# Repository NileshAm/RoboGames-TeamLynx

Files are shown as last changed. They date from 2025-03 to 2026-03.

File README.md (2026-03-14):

# TeamLynx

<p align="center">
  
</p>

<p align="center">
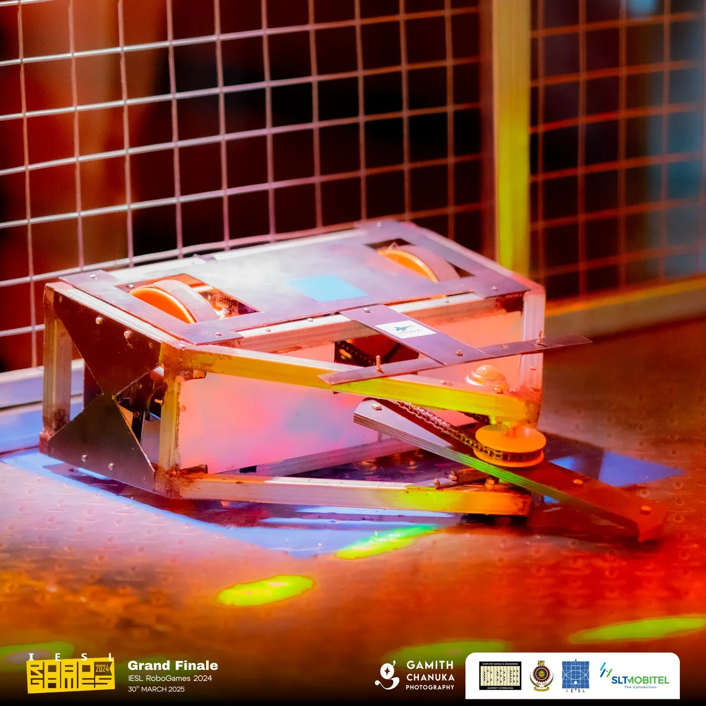
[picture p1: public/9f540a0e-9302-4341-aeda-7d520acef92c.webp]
  
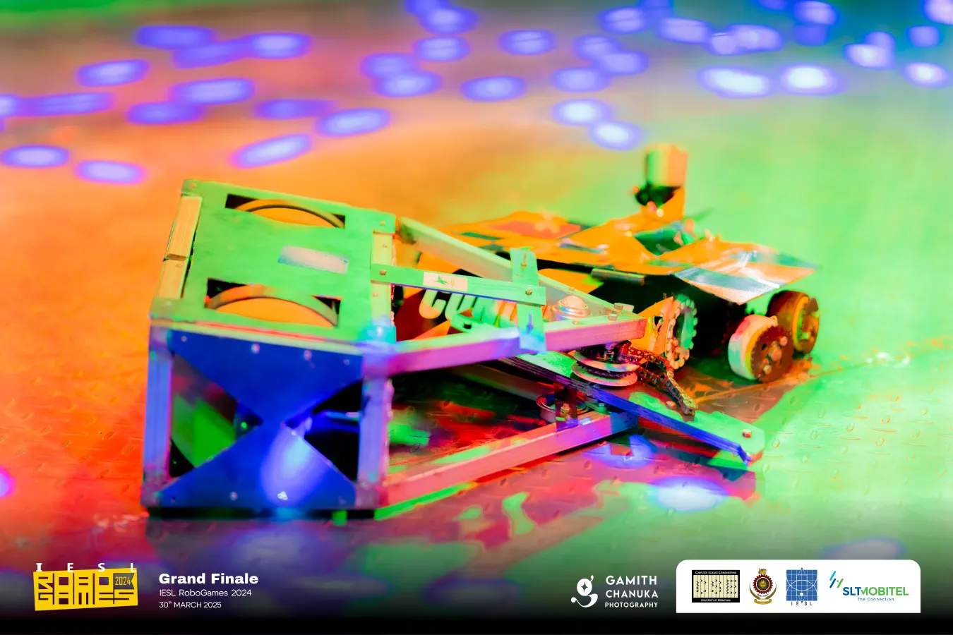
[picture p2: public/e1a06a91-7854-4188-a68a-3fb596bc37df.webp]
  
</p>

In this repository contains the project files for the Team-Lynx battlebot. 

## About
* All the 3D modelling and design is done through solidworks. Assembly can be found [here](drawings-pdf\AssemblyV2.pdf).
* The PCB design use done by using Altium designer.
* Firmware is being ran on a STM32 blue pill for its high performance characteristics.

## Project Structure

```
└── 📁RoboGames-TeamLynx
    └── 📁code
        ├── code.ino
        ├── motor_control.h
        ├── pins.h
        ├── receiver.h
        ├── restart.h
    └── 📁downloads
        └── 📁5840-31zys-1.snapshot.6
            ├── M8 long shaft.stl
            ├── STD D-Shaft.stl
        └── 📁8mm-lead-screw-with-nut-1.snapshot.2
            ├── LeadScrew 8mm x 2mmPitch.JPG
            ├── LeadScrew 8mm x 2mmPitch.SLDPRT
            ├── LeadScrew 8mm x 2mmPitch.STEP
            ├── LeadScrew Nut 8mm x 2mmPitch.JPG
            ├── LeadScrew Nut 8mm x 2mmPitch.SLDPRT
            ├── LeadScrew Nut 8mm x 2mmPitch.STEP
        └── 📁arduino-mega-2560--1.snapshot.8
            ├── ArduinoMega_STEP_AP203.STEP
            ├── ArduinoMega.SLDPRT
        └── 📁arduino-nano-7.snapshot.2
            ├── arduino nano.SLDPRT
        └── 📁avian-4250-800kv-outrunner-brushless....
            └── 📁Outrunner Motor
            ├── Outrunner Motor.STEP
            ├── Screenshot 2023-02-23 193953.png
        └── 📁bts7960-43a-high-power-h-.....
            ├── 8 PIN HEADER, IC, .....
            ├── ALUMINUM ELECTROLYTIC ...
        └── 📁dc-motor-zy6812-100-120w-1.snapshot.4
            ├── DC motor zy6812 100w.SLDPRT
            ├── DC motor zy6812 100w.STEP
            ├── untitled.26.jpg
        └── 📁kfl08-8mm-zinc-aluminum-alloy-....
        └── 📁simple-box-bar-frame-1.snapshot.1
            ├── 11 Table Frame.SLDPRT
    └── 📁drawings
        ├── arduino nano.SLDDRW
        ├── Assembly.SLDDRW
        ├── AssemblyV2.SLDDRW
        .
        .
        .
    └── 📁drawings-pdf
        ├── ArduinoNano.pdf
        ├── ArmourAnnotations.png
        .
        .
        .
        .
    └── 📁laserCutFiles
        ├── BackArmourPlate.DXF
        ├── BottomArmourPlatex2.DXF
        ├── CasterMountx2.DXF
        .
        .
        .
        .
    └── 📁Parts
        └── 📁Vis
            ├── Assembly.mp4
        ├── AcralicPlate.SLDPRT
        ├── arduino nano.SLDPRT
        .
        .
        .
        .
    └── 📁PCB
        └── 📁Lync-main-board
            └── 📁__Previews
                ├── Schematic.SchDocPreview
            └── 📁Integrated Library
                └── 📁ALSR0310K00FE12
                    ├── ALSR0310K00FE12.SchLib
                    ├── ALSR0310K00FE12.STEP
                    ├── RESAD1869W81L1270D457.PcbLib
                .
                .
                .
            └── 📁PCB library
                ├── LM2596S.PcbLib
            └── 📁Schematic library
                ├── LM2596S.SchLib
            ├── 2layer-2oz.RUL
            ├── Logo.png
            ├── Lync-main-board.PrjPcb
            ├── Lync-main-board.PrjPcbStructure
            ├── PCB.PcbDoc
            ├── schematic.pdf
            ├── Schematic.SchDoc
        ├── Lync-main-board.zip
    └── 📁public
        ├── 9f540a0e-9302-4341-aeda-7d520acef92c.webp
        ├── Assembly.glb
        ├── AssemblyV2.STEP
        ├── e1a06a91-7854-4188-a68a-3fb596bc37df.webp
    └── 📁sheet metal parts
        ├── Back brace.SLDPRT
        ├── Back horizontal brace.SLDPRT
        ├── Back plate.SLDPRT
        ├── blade mount.SLDASM
        ├── Bottom brace.SLDPRT
        ├── motor mount level 1.SLDPRT
        ├── motor mount level 2.SLDPRT
        ├── motor mount level 3.SLDPRT
        ├── Top brace.SLDPRT
    ├── .gitignore
    ├── LYNX logo.jpg
    └── README.md
```

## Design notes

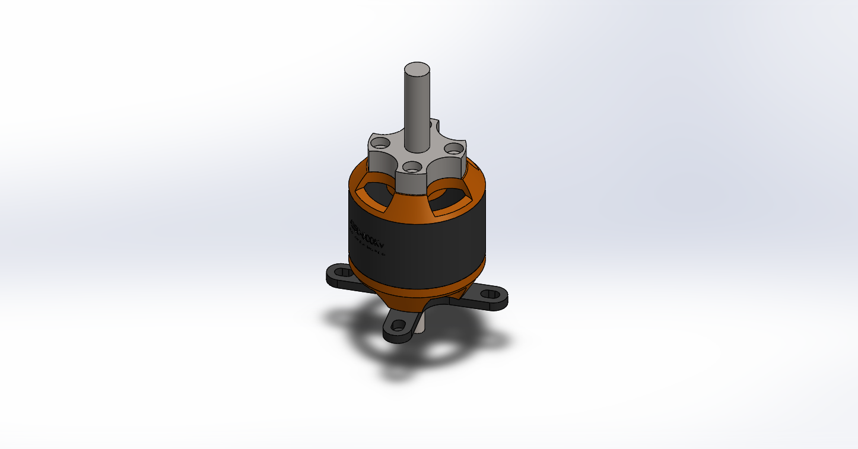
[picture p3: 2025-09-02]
downloads/avian-4250-800kv-outrunner-brushless-motor-1.snapshot.3/Screenshot 2023-02-23 193953.png

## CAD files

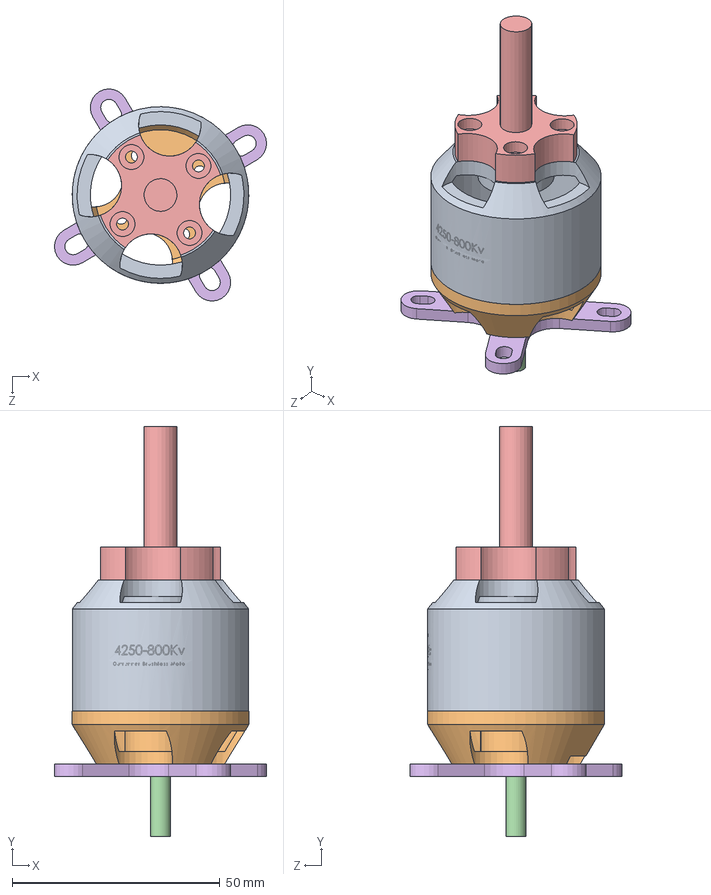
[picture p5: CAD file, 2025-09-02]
downloads/avian-4250-800kv-outrunner-brushless-motor-1.snapshot.3/Outrunner Motor/Outrunner Motor.SLDASM
51.0 x 98.6 x 51.0 mm
Outrunner Brushless Motor Top
Outrunner Brushless Motor Bottom
SimpleBearing
3.16Rod
PropShaft
MotorCrossBar

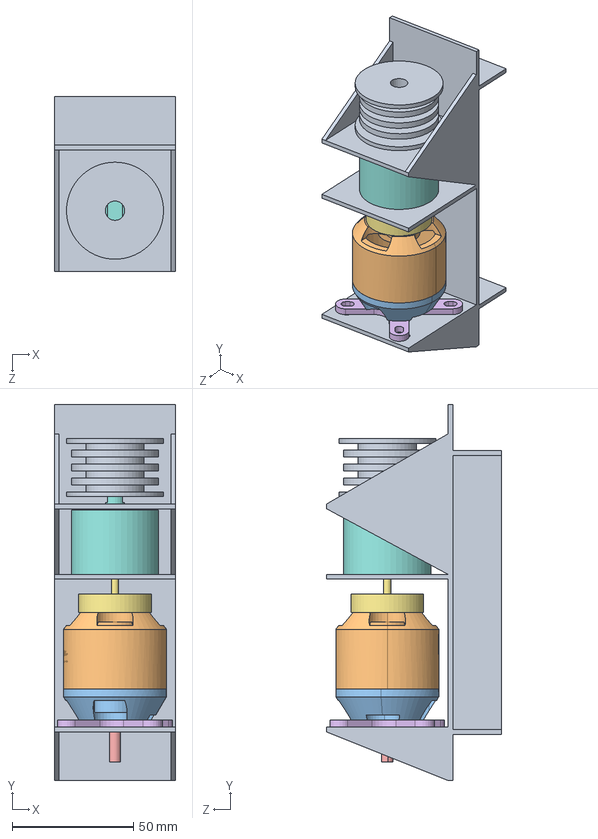
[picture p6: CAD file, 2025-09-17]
Parts/BladeMotorAssembly.SLDASM
50.0 x 155.0 x 72.0 mm
BladeMotorMount
Outrunner Brushless Motor Top.STEP
Outrunner Brushless Motor Bottom.STEP
SimpleBearing.STEP
3.16Rod.STEP
MotorCrossBar.STEP
BladeShaft
Gearbox
BladeMotorPulley

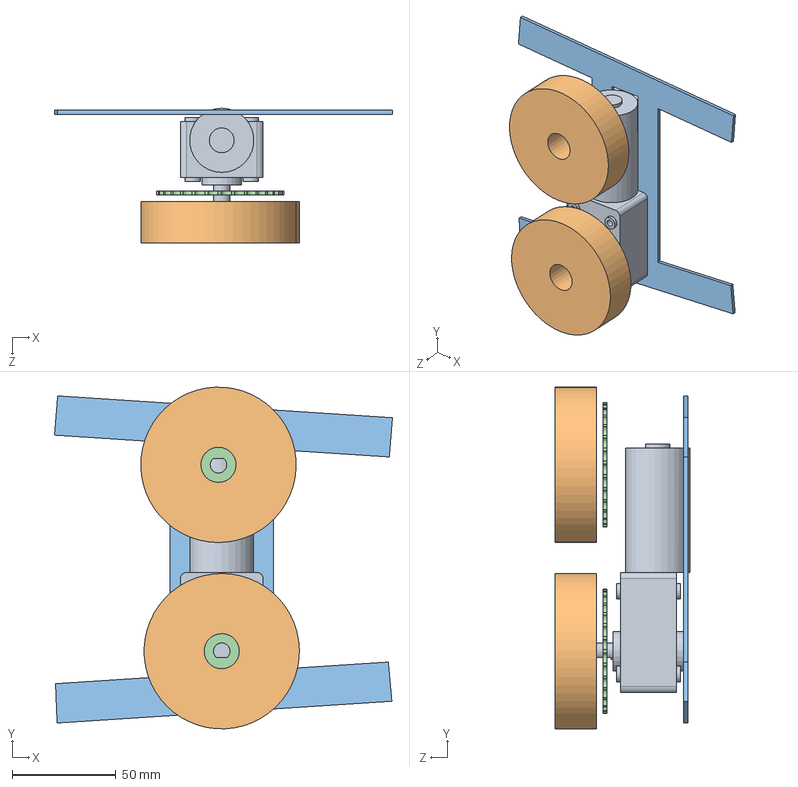
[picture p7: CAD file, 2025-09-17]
Parts/WheelMotorAssembly.SLDASM
163.2 x 164.9 x 65.0 mm
WheelMotor
Wheel x 2
motor mount
Sproket x 2

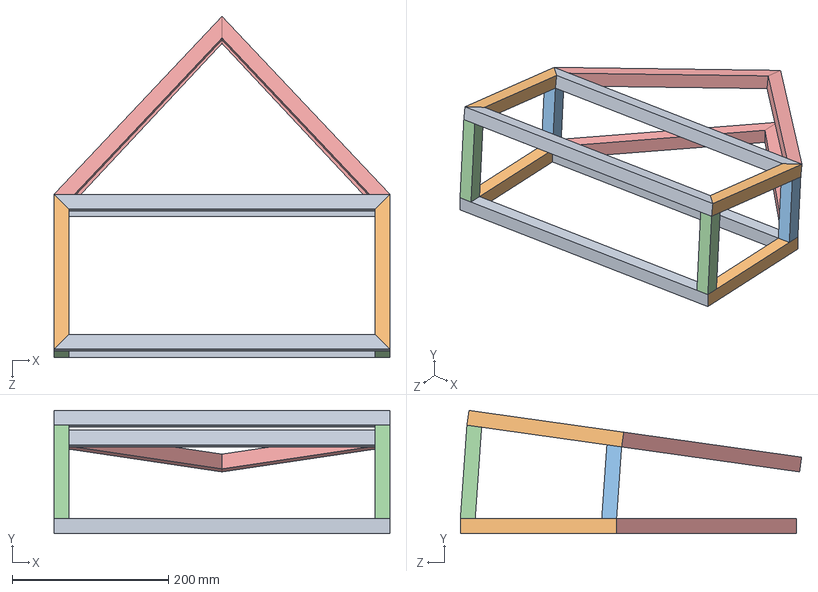
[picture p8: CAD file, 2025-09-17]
Parts/Frame.SLDASM
430.0 x 157.6 x 436.8 mm
FrontFrame x 4
RightFrame x 4
HeightFrameFront x 2
HeightFrame x 2
FrontSupportFrame x 4

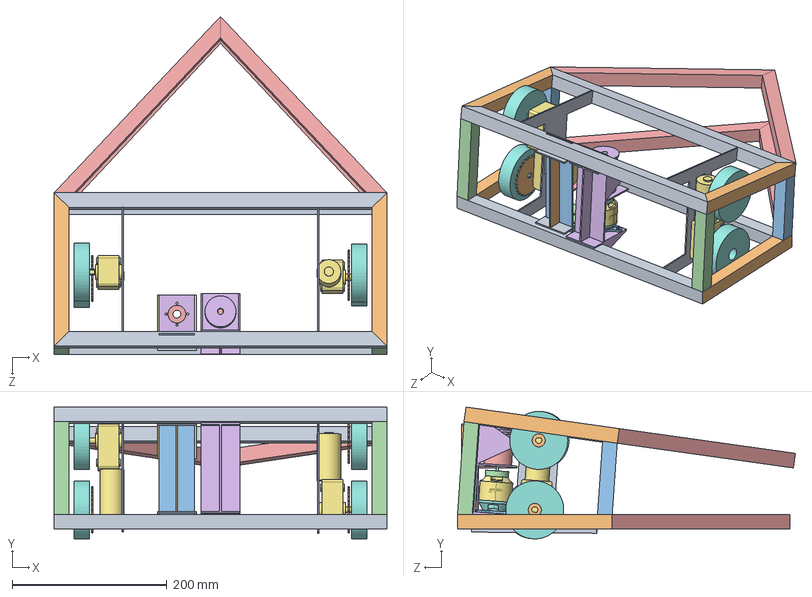
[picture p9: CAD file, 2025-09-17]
Parts/AssemblyV2.SLDASM
430.0 x 170.4 x 436.8 mm
FrontFrame x 4
RightFrame x 4
HeightFrameFront x 2
HeightFrame x 2
FrontSupportFrame x 4
BladeMotorMount
Outrunner Brushless Motor Top.STEP
Outrunner Brushless Motor Bottom.STEP
SimpleBearing.STEP
3.16Rod.STEP
MotorCrossBar.STEP
BladeShaft
Gearbox
BladeMotorPulley
WheelMotor x 2
Wheel x 4
motor mount x 2
Sproket x 2
Back plate
motor mount level 1
motor mount level 2
motor mount level 3
Top brace x 2
Bottom brace x 2
Back horizontal brace x 2
Back brace

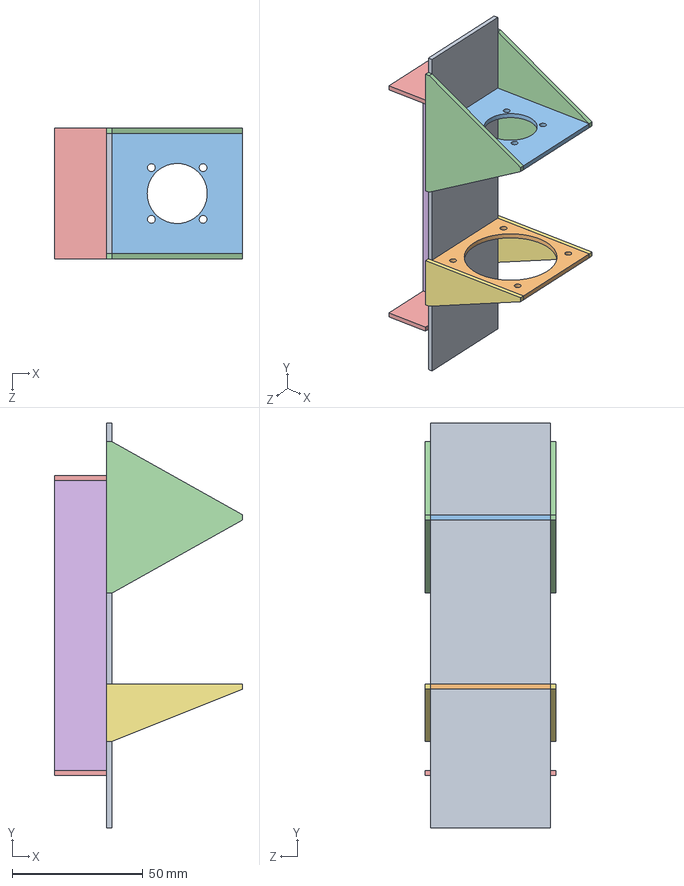
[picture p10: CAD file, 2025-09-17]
sheet metal parts/blade mount.SLDASM
72.0 x 155.0 x 50.0 mm
Back plate
motor mount level 2
motor mount level 3
Top brace x 2
Back horizontal brace x 2
Back brace
Bottom brace x 2

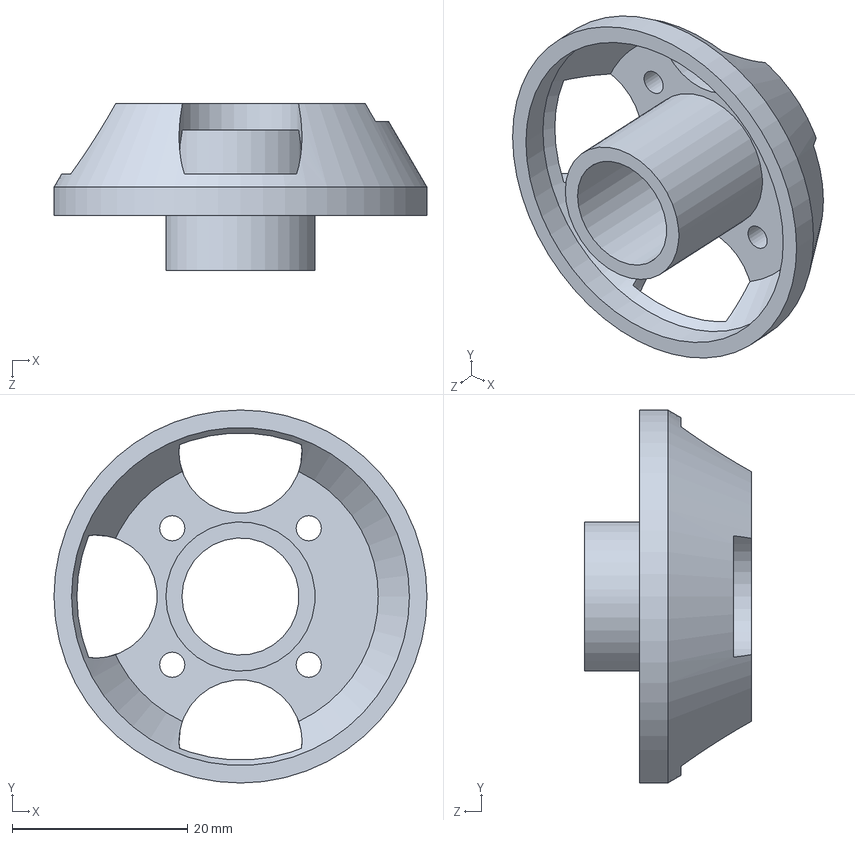
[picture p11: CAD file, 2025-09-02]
downloads/avian-4250-800kv-outrunner-brushless-motor-1.snapshot.3/Outrunner Motor/Outrunner Brushless Motor Bottom.SLDPRT
42.5 x 42.5 x 19.0 mm

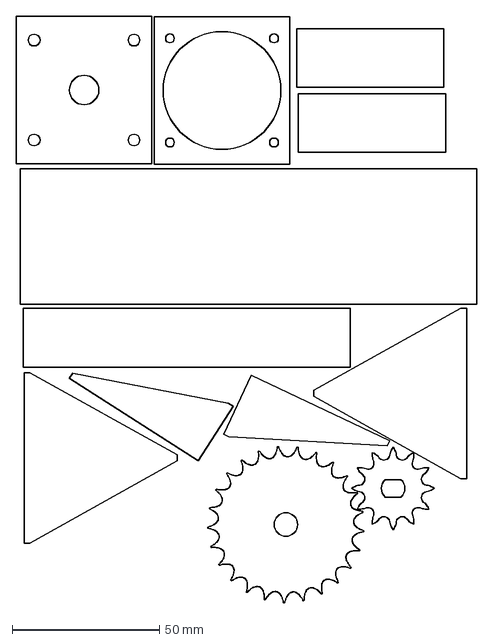
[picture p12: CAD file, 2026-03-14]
laserCutFiles/Motor mount sheetmetal.DXF
156.3 x 199.1 mm

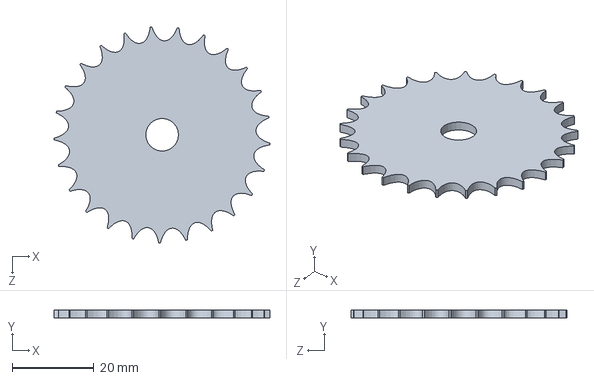
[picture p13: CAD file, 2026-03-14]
Parts/BladeSprocket.SLDPRT
52.9 x 2.00 x 52.9 mm

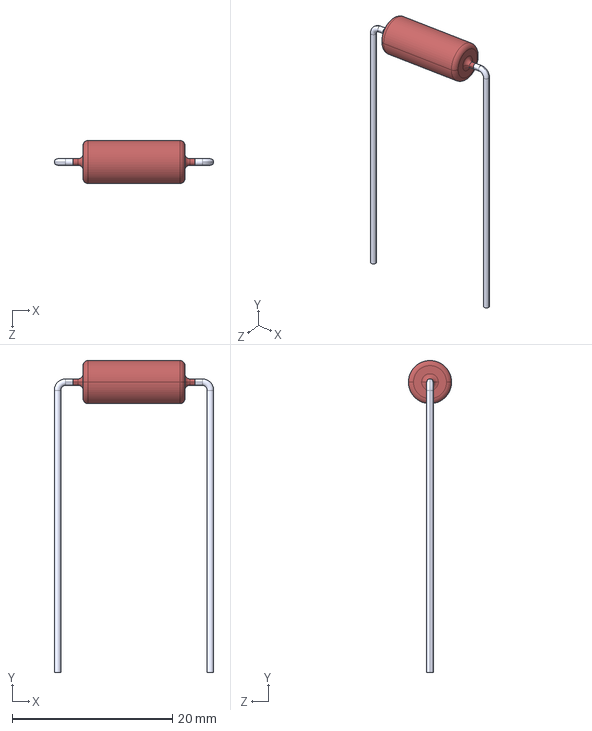
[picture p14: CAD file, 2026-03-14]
PCB/Lync-main-board/Integrated Library/ALSR0310K00FE12/ALSR0310K00FE12.STEP
19.9 x 38.9 x 5.38 mm

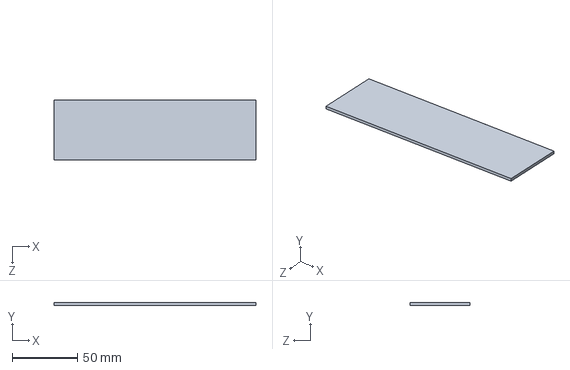
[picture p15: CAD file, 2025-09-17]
sheet metal parts/Back plate.SLDPRT
155.0 x 2.00 x 46.0 mm

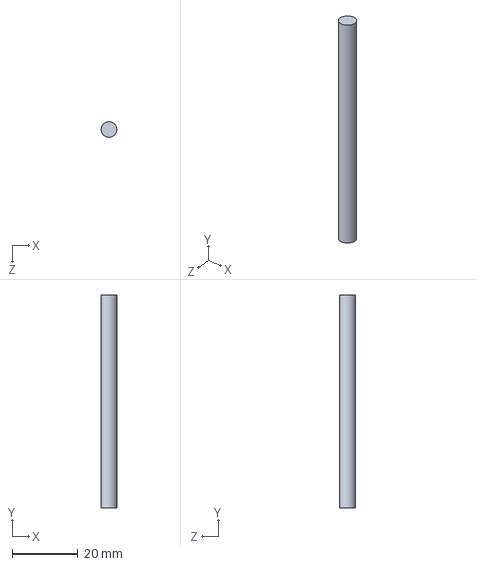
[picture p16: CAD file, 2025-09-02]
downloads/avian-4250-800kv-outrunner-brushless-motor-1.snapshot.3/Outrunner Motor/3.16Rod.SLDPRT
4.76 x 64.8 x 4.76 mm

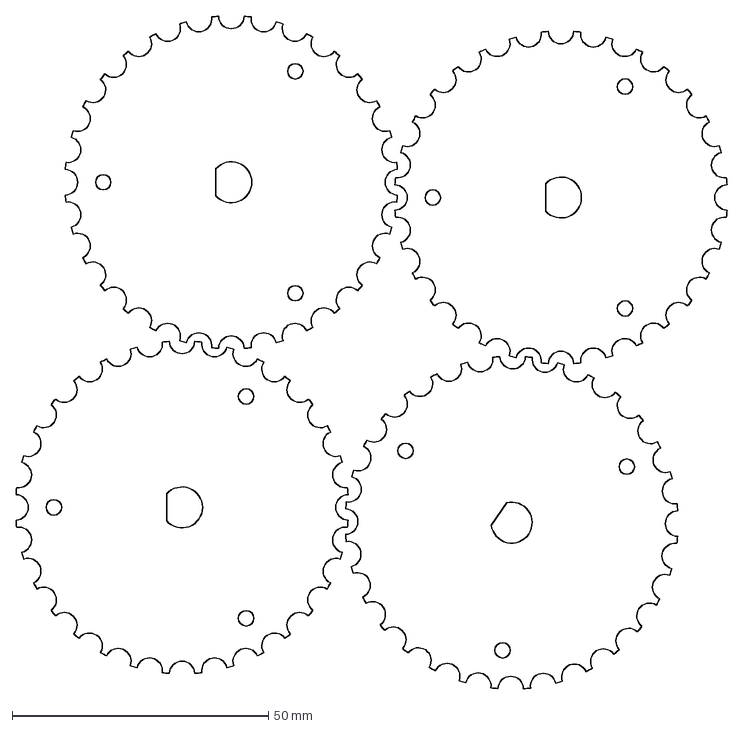
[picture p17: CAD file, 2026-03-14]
laserCutFiles/sprocket.DXF
138.8 x 131.2 mm

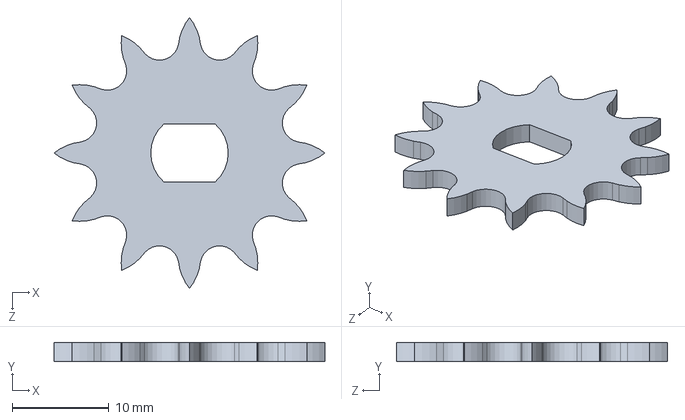
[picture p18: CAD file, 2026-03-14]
Parts/Motorsprocket.SLDPRT
28.0 x 2.00 x 28.0 mm

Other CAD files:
downloads/avian-4250-800kv-outrunner-brushless-motor-1.snapshot.3/Outrunner Motor.STEP
sheet metal parts/Back horizontal brace.SLDPRT
downloads/avian-4250-800kv-outrunner-brushless-motor-1.snapshot.3/Outrunner Motor/MotorCrossBar.SLDPRT
laserCutFiles/motor mount sprocket.DXF
Parts/BladeMotorMount.SLDPRT
Parts/BladeMotorPulley.SLDPRT
Parts/BladeShaft.SLDPRT
Parts/Gearbox.SLDPRT
Parts/Sproket.SLDPRT
Parts/Wheel.SLDPRT
Parts/WheelMotor.SLDPRT
Parts/WheelMotorMountBack.SLDPRT
Parts/motor mount.SLDPRT
downloads/avian-4250-800kv-outrunner-brushless-motor-1.snapshot.3/Outrunner Motor/Outrunner Brushless Motor Top.SLDPRT
downloads/avian-4250-800kv-outrunner-brushless-motor-1.snapshot.3/Outrunner Motor/PropShaft.SLDPRT
downloads/avian-4250-800kv-outrunner-brushless-motor-1.snapshot.3/Outrunner Motor/SimpleBearing.SLDPRT
laserCutFiles/Motor mount sheetmetal.SLDDRW
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

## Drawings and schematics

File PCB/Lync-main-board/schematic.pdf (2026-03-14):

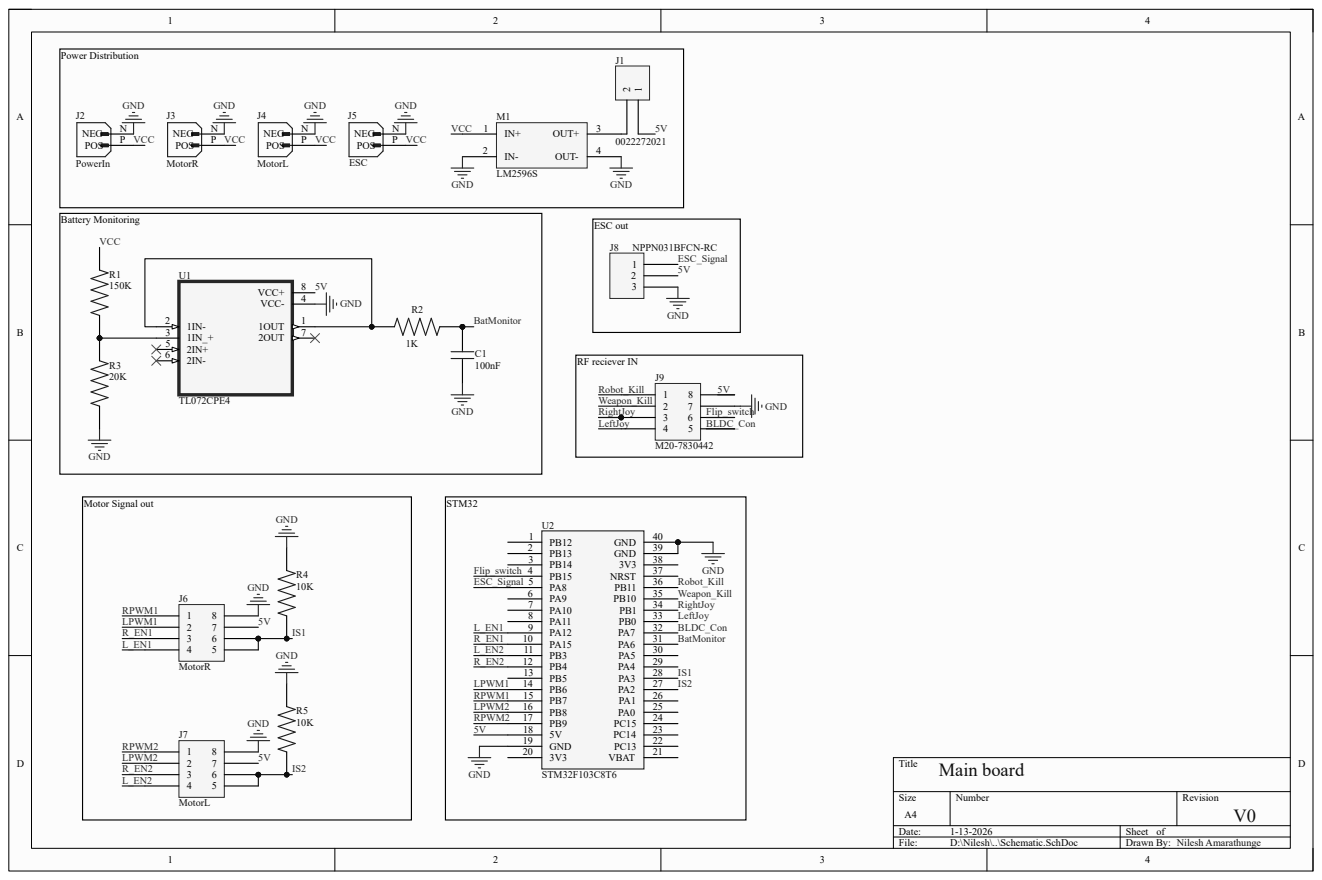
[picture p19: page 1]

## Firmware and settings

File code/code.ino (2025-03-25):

#include "pins.h"
#include "motor_control.h"
#include <Arduino.h>
#include "receiver.h"
#include "restart.h"

unsigned long lastSignalTime = 0; // Tracks last valid SBUS data
int prevWeapon = -1;              // Stores previous weapon value

void setup()
{
    Serial.begin(115200);

    // initilize reciever
    setupReciever();

    /* Initialize motors */
    setupMotors();
}

void loop()
{
    if (sbus_rx.Read())
    {
        /* Get SBUS data */
        data = sbus_rx.data();
        lastSignalTime = millis(); // Update last valid signal time

        // Map SBUS values to motor control range
        int throttle = map(data.ch[THROTTLE_CHANNEL], 172, 1811, 255, -255); // CH1: Throttle
        int steering = map(data.ch[STEERING_CHANNEL], 172, 1811, 255, -255); // CH2: Steering

        // 3-state switch (-1, 0, 1) -1 is the off state.
        int weaponState = map(data.ch[WEAPON_STATE_CHANNEL], 500, 1500, -1, 1); // 3-state switch (-1, 0, 1)

        int weapon = map(data.ch[WEAPON_CHANNEL], 172, 1811, 0, 255); // CH3: Weapon control
        bool killSwitch = (data.ch[KILL_SWITCH_CHANNEL] > 1000);      // CH6: Kill switch


        // Invert steering if that channel is high
        if (data.ch[STEERING_INVERT_CHANNEL] > 1000)
        {
            steering = -1 * steering;
            throttle = -1 * throttle;
        }

        /* Noise Filtering */
        if (abs(throttle) < NOISE_THRESHOLD)
            throttle = 0;
        if (abs(steering) < NOISE_THRESHOLD)
            steering = 0;
        if (weapon < NOISE_THRESHOLD)
            weapon = 0;

        /* Handle failsafe conditions */
        if (data.failsafe || killSwitch)
        {
            Serial.println("⚠️ EMERGENCY STOP! FAILSAFE or KILL SWITCH ACTIVE! ⚠️");
            throttle = 0;
            steering = 0;
            weapon = 0;

            // Stop all motors. not having below two lines can cause serious accidents.
            controlMotors(0, 0);
            controlWeapon(0);

            restart(); // Restart system if kill switch is toggled
        }

        if (data.lost_frame)
        {
            Serial.println("⚠️ FRAME LOST! ⚠️");
        }

        /* Send values to motor control */
        controlMotors(throttle, steering);

        /* Only update the weapon motor if the value changes */
        if (weapon != prevWeapon || weaponState == -1)
        {
            int pwmval;
            if (weaponState == -1)
            { // If weapon is off, stop the motor
                pwmval = 0;
            }
            else if (weaponState == 1)
            {
                pwmval = -1 * weapon; // Reverse the weapon direction
            }
            else
            {
                pwmval = weapon;
            }

            controlWeapon(pwmval);
            prevWeapon = weapon; // Update previous value
        }

        /* Debug Output */
        Serial.print("Throttle: ");
        Serial.print(throttle);
        Serial.print("\tSteering: ");
        Serial.print(steering);
        Serial.print("\tWeapon: ");
        Serial.println(weapon);
        Serial.print("\tKill Switch: ");
        Serial.println(killSwitch ? "ON" : "OFF");
    }

    /* No Signal Timeout - If no SBUS data received in TIMEOUT_MS, stop the bot */
    if (millis() - lastSignalTime > TIMEOUT_MS)
    {
        Serial.println("⛔ NO SIGNAL! STOPPING BOT ⛔");
        controlMotors(0, 0); // Stop all motors
        controlWeapon(0);
    }
}

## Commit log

2025-09-02 New design made.
    changed motor to brushless motor, changed wheel motors to be verticle, improved blade motor mount.
    [3.16Rod.SLDPRT, AssemblyV2.SLDASM, BladeMotorAssembly.SLDASM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]
2025-09-11 new design implemented.
    [AssemblyV2.SLDASM, BladeMotorAssembly.SLDASM, Frame.SLDASM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]
2025-09-11 dimentions adjested to match real model
    [AssemblyV2.SLDASM, BladeMotorAssembly.SLDASM, Frame.SLDASM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]
2025-09-17 blade motor mount modified,
    [AssemblyV2.SLDASM, Back brace.SLDPRT, Back horizontal brace.SLDPRT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]
2025-09-17 changed sprockets
    [BladeSprocket.SLDPRT, Motor mount sheetmetal.DXF, Motor mount sheetmetal.SLDDRW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]
2026-03-14 PCB implemented
    [ALSR0310K00FE12.STEP, ALSR0310K00FE12.SchLib, C320C.PcbLib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]
